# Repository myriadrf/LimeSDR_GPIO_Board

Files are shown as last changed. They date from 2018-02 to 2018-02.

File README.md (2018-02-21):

# LimeSDR GPIO Board

LimeSDR GPIO Board board

The [LimeSDR GPIO Board](https://myriadrf.org/projects/limesdr-gpio-board/) is an expansion board for the LimeSDR family that provides individually settable, bi-directional level-shifted I/O for FPGA GPIO 0-7. Each I/O has a high-voltage and power Darlington drive stage suitable for inductive loads, such as coaxial relays. 

* **Provides bi-directional level shifted IO for GPIO 0-7**
  * 1.2-5.5V IO on J2
* **Each IO has a high voltage and power Darlington drive stage**
  * Acceptable rating 30V 300mA (0-4) 200mA (5-7)
  * Suitable for inductive loads
* **Input/Output are individually switch-able**
* **LimeSDR form factor**
* **Individually pluggable relay connections**

## Contents

The directory structure is as follows:

      hardware/<variant>/<version>/
          Equivalent Circuits/
          Project Outputs/       - BOM, rule check reports, Gerbers, pick & place files, PDFs

      software/
          examples/		 - Simple software examples

## Changelog

| Version | Date | Summary
|---|---|---
| 0402 CAD2 | 21/02/18 | First production version |

## Licence

LimeSDR GPIO Board copyright 2018 [AB Open Ltd](https://abopen.com).

<br />This work is licensed under a <a rel="license" href="http://creativecommons.org/licenses/by/4.0/">Creative Commons Attribution 4.0 International License</a>.

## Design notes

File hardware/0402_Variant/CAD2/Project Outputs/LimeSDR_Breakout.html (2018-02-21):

# /home/karl/Documents/Projects/LimeGPIO/CAD2/LimeSDR_Breakout_0402_version/LimeSDR_Breakout.sch

Thu 30 Nov 2017 16:35:27 GMT

Eeschema 4.0.7-e2-6376~58~ubuntu16.04.1

Component Count:90

Ref | Qnty | Value | Part | Datasheet | Description | Vendor
C1, C3, C4, C6, C7, C8, C11, C12, C15, C16 | 10 | 1uF 16V 0402 | device:C | | Unpolarized capacitor
C2 | 1 | CP | device:CP | | Polarised capacitor
C9, C10, C13, C17, C18, C19, C20, C21 | 8 | 100nF 1206 50V | device:C | | Unpolarized capacitor
C14 | 1 | DNI | device:C | | Unpolarized capacitor
D1 | 1 | GS0T03C_SOT23 | device:D_TVS_x2_AAC | | Bidirectional dual transient-voltage-suppression (TVS) diode (center=pin3)
D2, D3, D4, D5, D6, D7, D8, D9 | 8 | LED | device:LED | | LED generic
J1, J23 | 2 | CONN_02X05 | LimeSDR_Breakout-cache:CONN_02X05
J2 | 1 | CONN_02X05 | LimeSDR_Breakout-cache:CONN_02X05
J3 | 1 | CONN_01X02 | LimeSDR_Breakout-cache:CONN_01X02
J4, J5 | 2 | Screw_Terminal_1x08 | LimeSDR_Breakout-cache:Screw_Terminal_1x08
J6 | 1 | Screw_Terminal_1x02 | LimeSDR_Breakout-cache:Screw_Terminal_1x02
Q1, Q2, Q3, Q4, Q5, Q6, Q7, Q8 | 8 | BC847 | transistors:BC847 | | 45V Vce, 0.8A Ic, NPN, SOT-23
R1, R2, R3, R4, R5, R6, R7, R8 | 8 | 0R | device:R | | Resistor
R25, R26, R27, R28, R29, R30, R31, R32 | 8 | DNI | device:R | | Resistor
R33, R34, R39, R40, R45, R46, R51, R52 | 8 | 47k | device:R | | Resistor
R37, R38, R43, R44, R49, R50, R55, R56 | 8 | 220R | device:R | | Resistor
RN1 | 1 | 10K | device:R_Pack04 | | 4 Resistor network, parallel topology, DIP package
RN2 | 1 | 10k | device:R_Pack04 | | 4 Resistor network, parallel topology, DIP package
SW1 | 1 | DIP_8_SW_IKD0803101 | LimeSDR_Breakout-cache:DIP_8_SW
U1, U2, U3 | 3 | ULN2003A | interface:ULN2003A | | High Voltage, High Current Darlington Transistor Arrays
U4, U5, U6, U7, U8, U9, U10, U11 | 8 | 74LVC1T45 | ABOpen:74LVC1T45

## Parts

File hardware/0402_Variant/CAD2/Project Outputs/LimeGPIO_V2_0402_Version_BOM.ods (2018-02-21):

Ref | Qnty | Kit 100 | Kit 60 | Kit QTY | Value | Footprint | Description | RS PN | ManfPN
C1, C3, C4, C6, C7, C8, C11, C12, C15, C16 | 10 | 1000 | 600 | Reel(90% Full) | 1uF 10V 0402 | 0402 | Unpolarized capacitor |  | C0402C105K8PAC7867
C2 | 1 | 100 | 60 | Bag 50 x2 | CP | TH | Polarised capacitor | 440-6575 | SK063M0100B5S-1012
C9, C10, C13, C17, C18, C19, C20, C21 | 8 | 800 | 480 | Reel(4000) | 100nF 1206 50V | 1206 | Unpolarized capacitor | 870-2776 | C1206C104K5RACTU
D1 | 1 | 100 | 60 | Reel(250) | GS0T03C_SOT23 | SOT23 | Bidirectional dual transient-voltage-suppression (TVS) diode (center=pin3) | 699-7957P | GSOT03C-E3-08
D2, D3, D4, D5, D6, D7, D8, D9 | 8 | 800 | 480 | Reel(4000) | LED | 0805 | LED generic (green) | 121-7785 | LG971
J23 | 1 | 100 | 60 | Tube 80 | CONN_02X05 | SM |  | 451-663 | FTSH-105-04-F-DV
J2 | 1 | 100 | 60 | Tube 120 | CONN_02X05 | SM |  |  | HTSS-105-01-T-DW
J3 | 1 | 100 | 60 | Bag 25x4 | CONN_01X02 | TH |  | 251-8086 | W81102T3825RC
J4, J5 | 2 | 200 | 120 | Box Loose x120 | Screw_Terminal_1x08 | TH |  | 189-6161 | 1757307
J6 | 1 | 100 | 60 | Bag loose 12x5 | Screw_Terminal_1x02 | TH |  | 189-6105 | 1757242
Q1, Q2, Q3, Q4, Q5, Q6, Q7, Q8 | 8 | 800 | 480 | Reel(90% Full) | BC847 | SOT23 | 45V Vce, 0.8A Ic, NPN, SOT-23 | 717-1578 | BC847C
R1, R2, R3, R4, R5, R6, R7, R8 | 8 | 800 | 480 | Reel(70% Full) | 0R | 0402 | Resistor |  | RC0402JR-070RL
R33, R34, R39, R40, R45, R46, R51, R52 | 8 | 800 | 480 | Reel(90% Full) | 47k | 0402 | Resistor |  | KMB-1610310072
R37, R38, R43, R44, R49, R50, R55, R56 | 8 | 800 | 480 | Reel(70% Full) | 220R | 0402 | Resistor |  | KMB-1701190047
RN1,RN2 | 1 | 100 | 60 | Reel(300) | 10K | 4x0603 | 4 Resistor network, parallel topology, DIP package | 426-229P | CAY16-103J4LF
SW1 | 1 | 100 | 60 | Tube 104 | DIP_8_SW_IKD0803101 | SM |  | 189-6010 | IKD0803101
U1, U2, U3 | 3 | 300 | 180 | Reelx2(200+200) | ULN2003A | SOIC | High Voltage, High Current Darlington Transistor Arrays | 251-8503 | ULN2003D1013TR
U4, U5, U6, U7, U8, U9, U10, U11 | 8 | 800 | 480 | Reel(3000) | 74LVC1T45 | SC70 – 6pin |  | 922-2385 | SN74LVC1T45DCKR

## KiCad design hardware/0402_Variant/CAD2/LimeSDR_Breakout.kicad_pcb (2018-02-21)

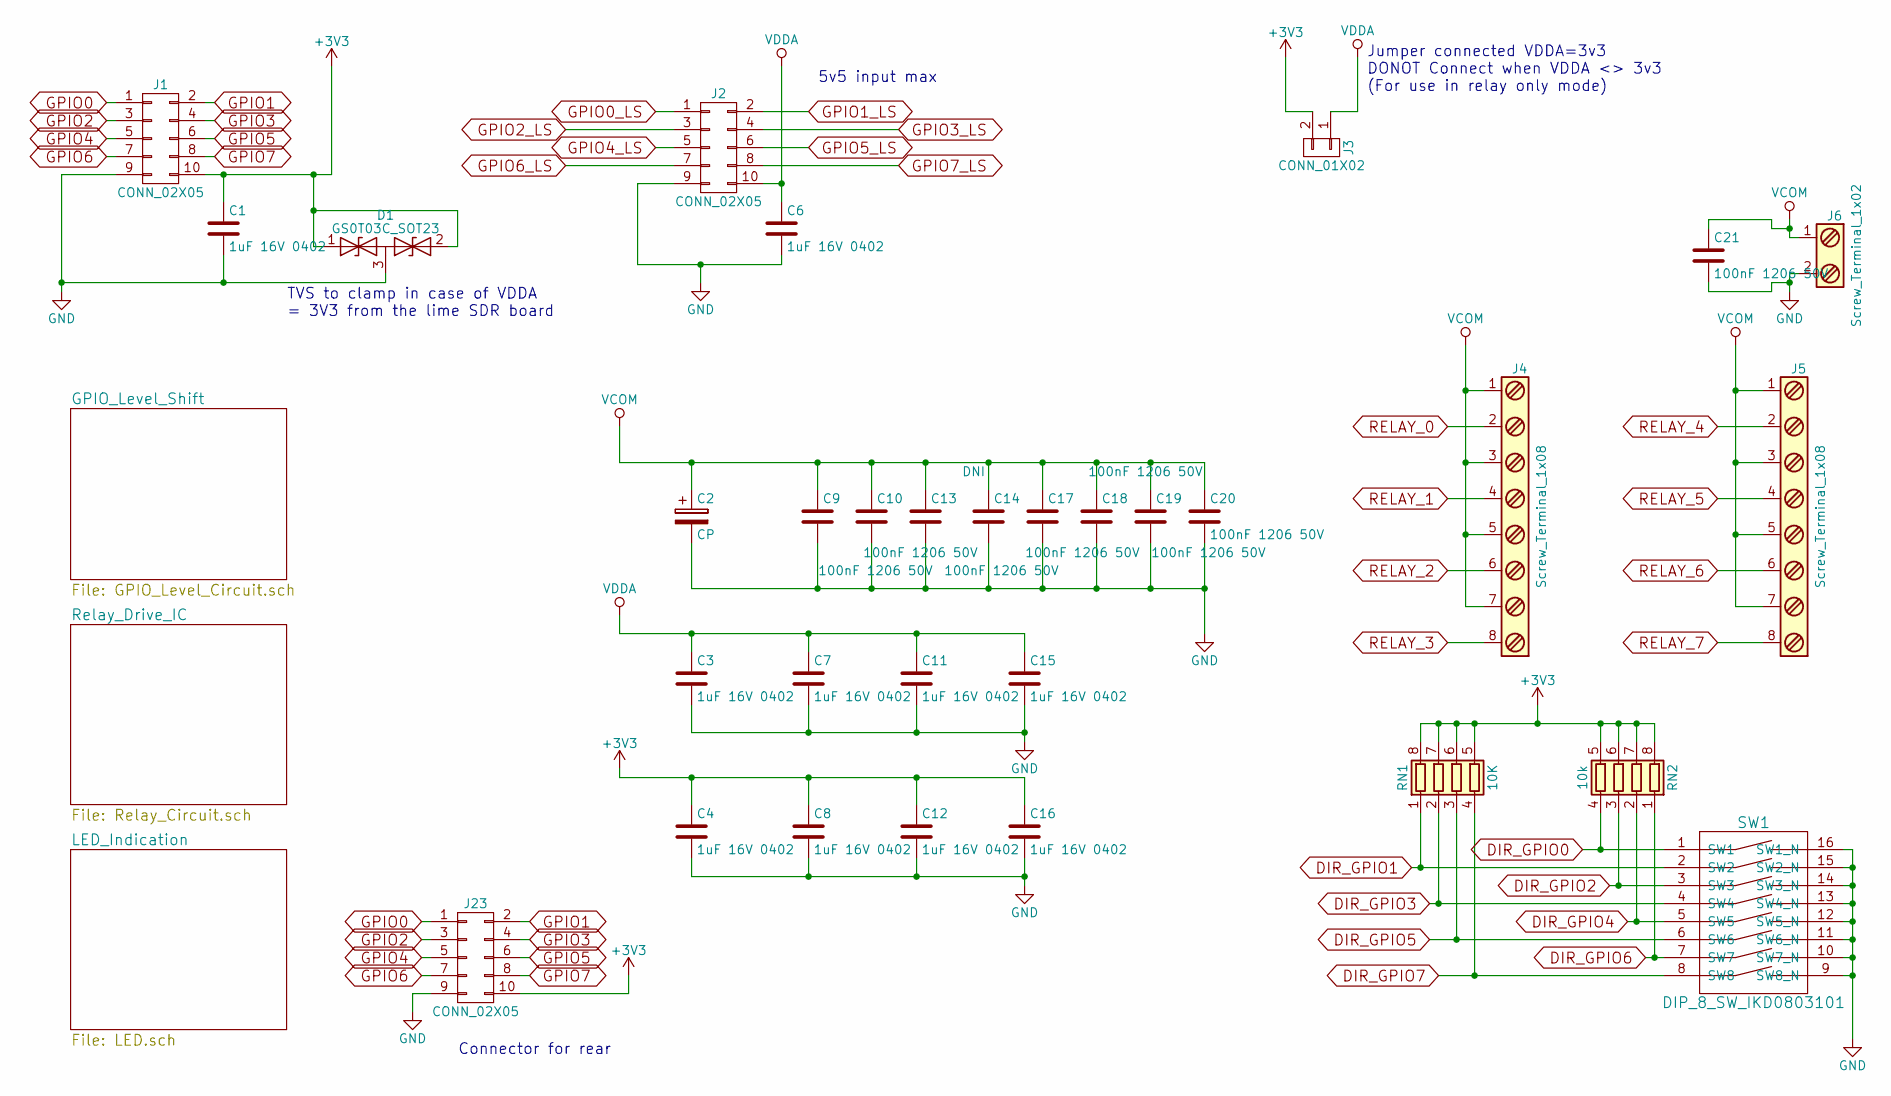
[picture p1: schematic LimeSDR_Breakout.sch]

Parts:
C1, C3, C4, C6, C7, C8, C11, C12, C15, C16: 1uF 16V 0402; C_0402
C2: CP; CP_Radial_D10.0mm_P5.00mm
C9, C10, C13, C17, C18, C19, C20, C21: 100nF 1206 50V; C_1206
C14: DNI; C_1206
D1: GS0T03C_SOT23; SOT-23
J1, J23: CONN_02X05; Pin_Header_Straight_2x05_Pitch1.27mm_SMD
J2: CONN_02X05; Pin_Header_Straight_2x05_Pitch2.54mm_SMD
J3: CONN_01X02; Pin_Header_Straight_1x02_Pitch2.54mm
J4, J5: Screw_Terminal_1x08; RS_189_6060_R
J6: Screw_Terminal_1x02; RS_189-6105_reversed
RN1: 10K; R_Array_Convex_4x1206
RN2: 10k; R_Array_Convex_4x1206
SW1: DIP_8_SW_IKD0803101; DIP_W7.40_Gull-Wing-J

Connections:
+3V3: C1.1, C4.1, C8.1, C12.1, C16.1, D1.1 (A1), D1.2 (A2), J1.10, J3.2, J23.10, RN1.5 (R4.2), RN1.6 (R3.2), RN1.7 (R2.2), RN1.8 (R1.2), RN2.5 (R4.2), RN2.6 (R3.2), RN2.7 (R2.2), RN2.8 (R1.2); also elsewhere on the board
DIR_GPIO0: RN2.4 (R4.1), SW1.1 (SW1); also elsewhere on the board
DIR_GPIO1: RN1.1 (R1.1), SW1.2 (SW2); also elsewhere on the board
DIR_GPIO2: RN2.3 (R3.1), SW1.3 (SW3); also elsewhere on the board
DIR_GPIO3: RN1.2 (R2.1), SW1.4 (SW4); also elsewhere on the board
DIR_GPIO4: RN2.2 (R2.1), SW1.5 (SW5); also elsewhere on the board
DIR_GPIO5: RN1.3 (R3.1), SW1.6 (SW6); also elsewhere on the board
DIR_GPIO6: RN2.1 (R1.1), SW1.7 (SW7); also elsewhere on the board
DIR_GPIO7: RN1.4 (R4.1), SW1.8 (SW8); also elsewhere on the board
GND: C1.2, C2.2, C3.2, C4.2, C6.2, C7.2, C8.2, C9.2, C10.2, C11.2, C12.2, C13.2, C14.2, C15.2, C16.2, C17.2, C18.2, C19.2, C20.2, C21.2, D1.3 (common), J1.9, J2.9, J6.2, J23.9, SW1.9 (SW8_N), SW1.10 (SW7_N), SW1.11 (SW6_N), SW1.12 (SW5_N), SW1.13 (SW4_N), SW1.14 (SW3_N), SW1.15 (SW2_N), SW1.16 (SW1_N); also elsewhere on the board
GPIO0: J1.1, J23.1; also elsewhere on the board
GPIO0_LS: J2.1; also elsewhere on the board
GPIO1: J1.2, J23.2; also elsewhere on the board
GPIO1_LS: J2.2; also elsewhere on the board
GPIO2: J1.3, J23.3; also elsewhere on the board
GPIO2_LS: J2.3; also elsewhere on the board
GPIO3: J1.4, J23.4; also elsewhere on the board
GPIO3_LS: J2.4; also elsewhere on the board
GPIO4: J1.5, J23.5; also elsewhere on the board
GPIO4_LS: J2.5; also elsewhere on the board
GPIO5: J1.6, J23.6; also elsewhere on the board
GPIO5_LS: J2.6; also elsewhere on the board
GPIO6: J1.7, J23.7; also elsewhere on the board
GPIO6_LS: J2.7; also elsewhere on the board
GPIO7: J1.8, J23.8; also elsewhere on the board
GPIO7_LS: J2.8; also elsewhere on the board
RELAY_0: J4.2; also elsewhere on the board
RELAY_1: J4.4; also elsewhere on the board
RELAY_2: J4.6; also elsewhere on the board
RELAY_3: J4.8; also elsewhere on the board
RELAY_4: J5.2; also elsewhere on the board
RELAY_5: J5.4; also elsewhere on the board
RELAY_6: J5.6; also elsewhere on the board
RELAY_7: J5.8; also elsewhere on the board
VCOM: C2.1, C9.1, C10.1, C13.1, C14.1, C17.1, C18.1, C19.1, C20.1, C21.1, J4.1, J4.3, J4.5, J4.7, J5.1, J5.3, J5.5, J5.7, J6.1; also elsewhere on the board
VDDA: C3.1, C6.1, C7.1, C11.1, C15.1, J2.10, J3.1; also elsewhere on the board

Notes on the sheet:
5v5 input max
TVS to clamp in case of VDDA = 3V3 from the lime SDR board
Jumper connected VDDA=3v3 DONOT Connect when VDDA <> 3v3 (For use in relay only mode)
Connector for rear

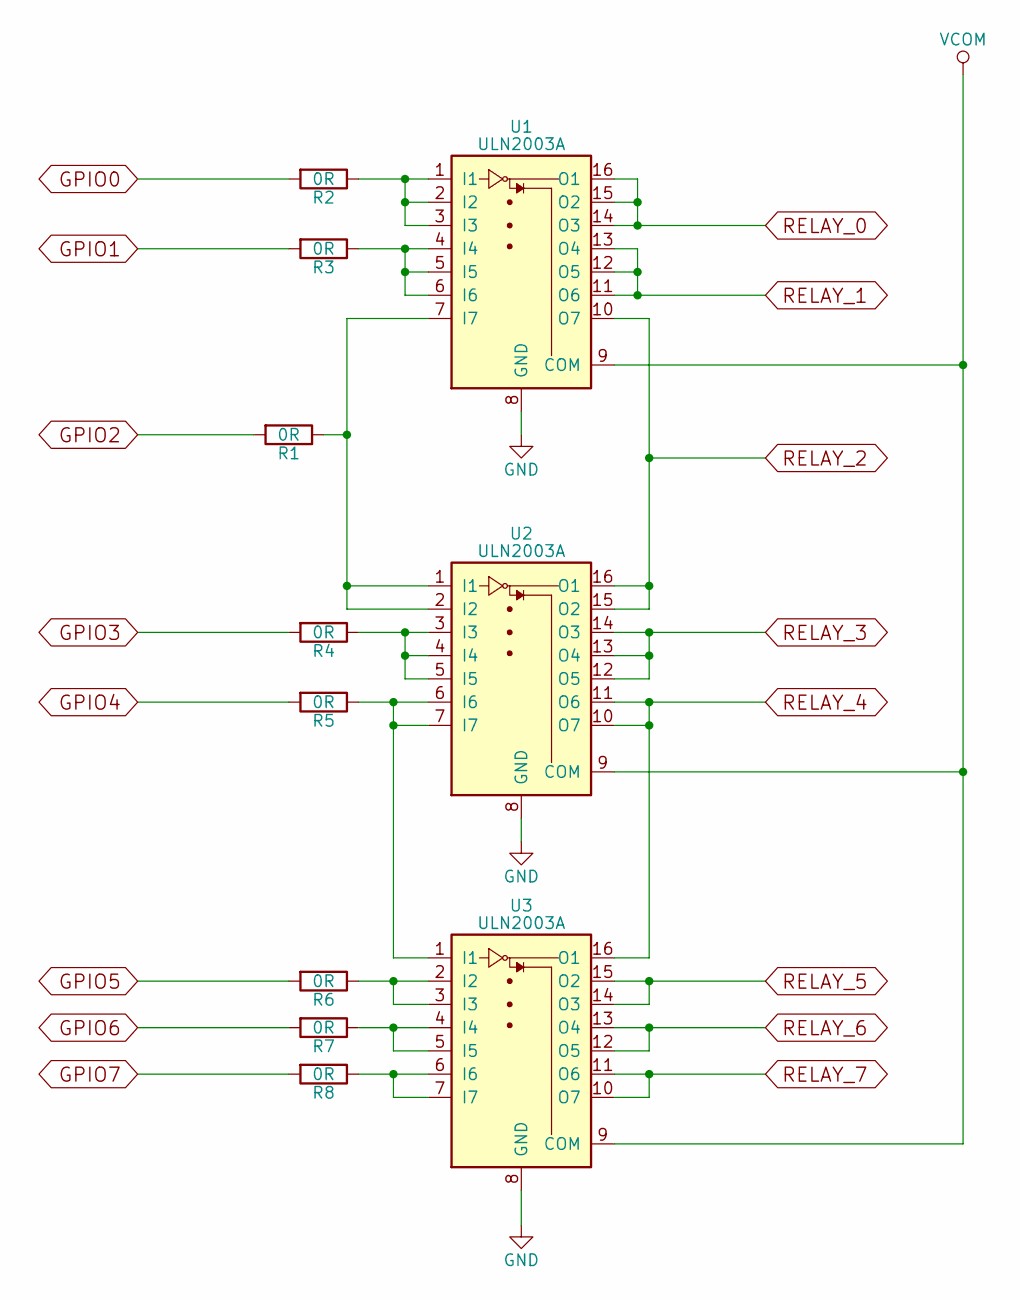
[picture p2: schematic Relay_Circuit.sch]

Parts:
R1, R2, R3, R4, R5, R6, R7, R8: 0R; C_0402
U1, U2, U3: ULN2003A; SOIC-16_3.9x9.9mm_Pitch1.27mm

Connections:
GND: U1.8 (GND), U2.8 (GND), U3.8 (GND); also elsewhere on the board
GPIO0: R2.2; also elsewhere on the board
GPIO1: R3.2; also elsewhere on the board
GPIO2: R1.2; also elsewhere on the board
GPIO3: R4.2; also elsewhere on the board
GPIO4: R5.2; also elsewhere on the board
GPIO5: R6.2; also elsewhere on the board
GPIO6: R7.2; also elsewhere on the board
GPIO7: R8.2; also elsewhere on the board
unnamed: R1.1, U1.7 (I7), U2.1 (I1), U2.2 (I2)
unnamed: R2.1, U1.1 (I1), U1.2 (I2), U1.3 (I3)
unnamed: R3.1, U1.4 (I4), U1.5 (I5), U1.6 (I6)
unnamed: R4.1, U2.3 (I3), U2.4 (I4), U2.5 (I5)
unnamed: R5.1, U2.6 (I6), U2.7 (I7), U3.1 (I1)
unnamed: R6.1, U3.2 (I2), U3.3 (I3)
unnamed: R7.1, U3.4 (I4), U3.5 (I5)
unnamed: R8.1, U3.6 (I6), U3.7 (I7)
RELAY_0: U1.14 (O3), U1.15 (O2), U1.16 (O1); also elsewhere on the board
RELAY_1: U1.11 (O6), U1.12 (O5), U1.13 (O4); also elsewhere on the board
RELAY_2: U1.10 (O7), U2.15 (O2), U2.16 (O1); also elsewhere on the board
RELAY_3: U2.12 (O5), U2.13 (O4), U2.14 (O3); also elsewhere on the board
RELAY_4: U2.10 (O7), U2.11 (O6), U3.16 (O1); also elsewhere on the board
RELAY_5: U3.14 (O3), U3.15 (O2); also elsewhere on the board
RELAY_6: U3.12 (O5), U3.13 (O4); also elsewhere on the board
RELAY_7: U3.10 (O7), U3.11 (O6); also elsewhere on the board
VCOM: U1.9 (COM), U2.9 (COM), U3.9 (COM); also elsewhere on the board

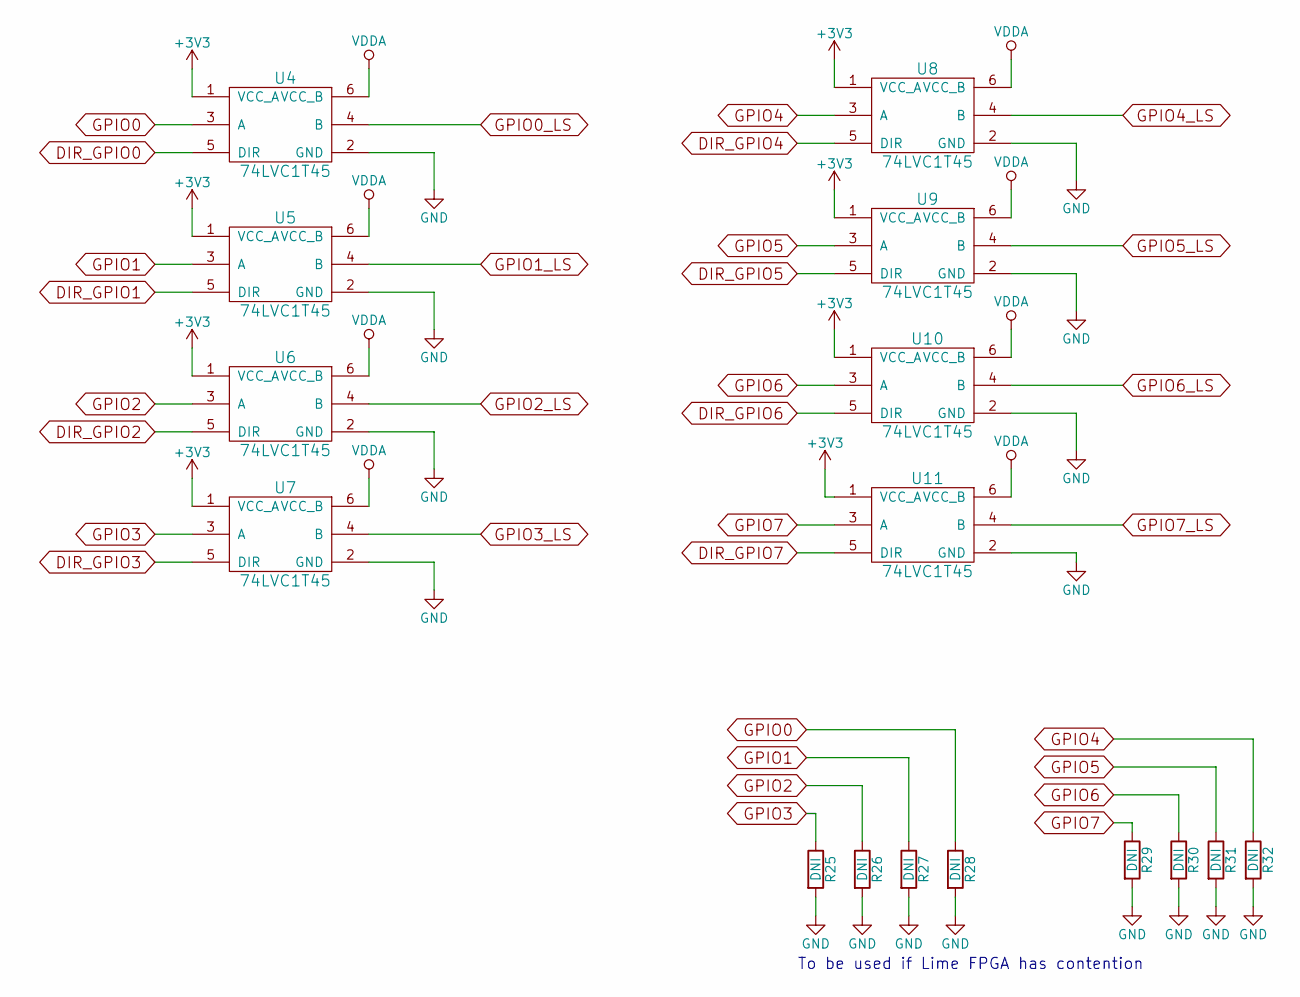
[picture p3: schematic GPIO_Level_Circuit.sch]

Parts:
R25, R26, R27, R28, R29, R30, R31, R32: DNI; C_0402
U4, U5, U6, U7, U8, U9, U10, U11: 74LVC1T45; SOT-363_SC-70-6_Handsoldering

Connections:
+3V3: U4.1 (VCC_A), U5.1 (VCC_A), U6.1 (VCC_A), U7.1 (VCC_A), U8.1 (VCC_A), U9.1 (VCC_A), U10.1 (VCC_A), U11.1 (VCC_A); also elsewhere on the board
DIR_GPIO0: U4.5 (DIR); also elsewhere on the board
DIR_GPIO1: U5.5 (DIR); also elsewhere on the board
DIR_GPIO2: U6.5 (DIR); also elsewhere on the board
DIR_GPIO3: U7.5 (DIR); also elsewhere on the board
DIR_GPIO4: U8.5 (DIR); also elsewhere on the board
DIR_GPIO5: U9.5 (DIR); also elsewhere on the board
DIR_GPIO6: U10.5 (DIR); also elsewhere on the board
DIR_GPIO7: U11.5 (DIR); also elsewhere on the board
GND: R25.2, R26.2, R27.2, R28.2, R29.2, R30.2, R31.2, R32.2, U4.2 (GND), U5.2 (GND), U6.2 (GND), U7.2 (GND), U8.2 (GND), U9.2 (GND), U10.2 (GND), U11.2 (GND); also elsewhere on the board
GPIO0: R28.1, U4.3 (A); also elsewhere on the board
GPIO0_LS: U4.4 (B); also elsewhere on the board
GPIO1: R27.1, U5.3 (A); also elsewhere on the board
GPIO1_LS: U5.4 (B); also elsewhere on the board
GPIO2: R26.1, U6.3 (A); also elsewhere on the board
GPIO2_LS: U6.4 (B); also elsewhere on the board
GPIO3: R25.1, U7.3 (A); also elsewhere on the board
GPIO3_LS: U7.4 (B); also elsewhere on the board
GPIO4: R32.1, U8.3 (A); also elsewhere on the board
GPIO4_LS: U8.4 (B); also elsewhere on the board
GPIO5: R31.1, U9.3 (A); also elsewhere on the board
GPIO5_LS: U9.4 (B); also elsewhere on the board
GPIO6: R30.1, U10.3 (A); also elsewhere on the board
GPIO6_LS: U10.4 (B); also elsewhere on the board
GPIO7: R29.1, U11.3 (A); also elsewhere on the board
GPIO7_LS: U11.4 (B); also elsewhere on the board
VDDA: U4.6 (VCC_B), U5.6 (VCC_B), U6.6 (VCC_B), U7.6 (VCC_B), U8.6 (VCC_B), U9.6 (VCC_B), U10.6 (VCC_B), U11.6 (VCC_B); also elsewhere on the board

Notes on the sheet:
To be used if Lime FPGA has contention

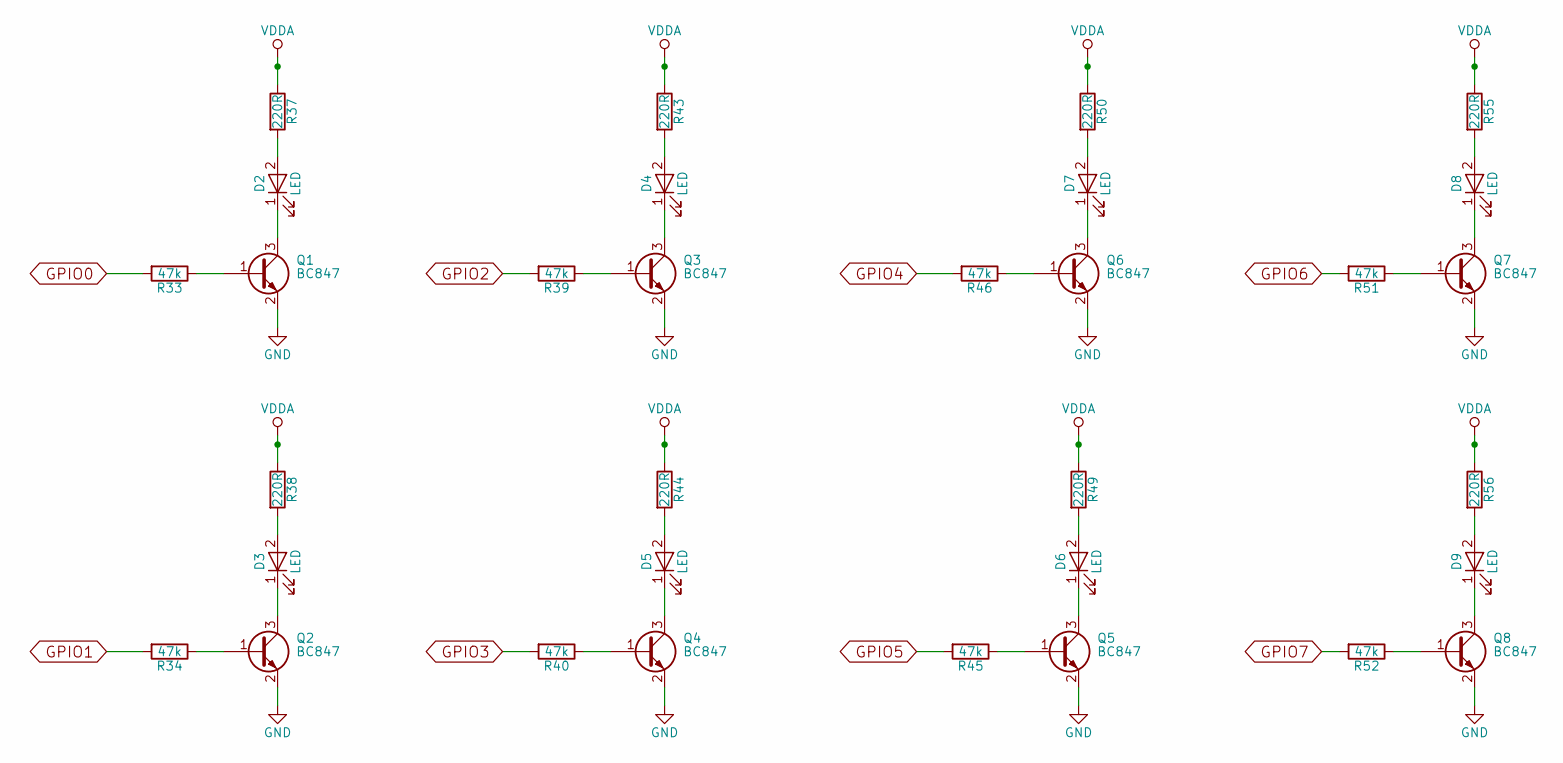
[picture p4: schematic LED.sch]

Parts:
D2, D3, D4, D5, D6, D7, D8, D9: LED; LED_0805
Q1, Q2, Q3, Q4, Q5, Q6, Q7, Q8: BC847; SOT-23
R33, R34, R39, R40, R45, R46, R51, R52: 47k; C_0402
R37, R38, R43, R44, R49, R50, R55, R56: 220R; C_0402

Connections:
GND: Q1.2 (E), Q2.2 (E), Q3.2 (E), Q4.2 (E), Q5.2 (E), Q6.2 (E), Q7.2 (E), Q8.2 (E); also elsewhere on the board
GPIO0: R33.2; also elsewhere on the board
GPIO1: R34.2; also elsewhere on the board
GPIO2: R39.2; also elsewhere on the board
GPIO3: R40.2; also elsewhere on the board
GPIO4: R46.2; also elsewhere on the board
GPIO5: R45.2; also elsewhere on the board
GPIO6: R51.2; also elsewhere on the board
GPIO7: R52.2; also elsewhere on the board
unnamed: D2.1 (K), Q1.3 (C)
unnamed: D2.2 (A), R37.2
unnamed: D3.1 (K), Q2.3 (C)
unnamed: D3.2 (A), R38.2
unnamed: D4.1 (K), Q3.3 (C)
unnamed: D4.2 (A), R43.2
unnamed: D5.1 (K), Q4.3 (C)
unnamed: D5.2 (A), R44.2
unnamed: D6.1 (K), Q5.3 (C)
unnamed: D6.2 (A), R49.2
unnamed: D7.1 (K), Q6.3 (C)
unnamed: D7.2 (A), R50.2
unnamed: D8.1 (K), Q7.3 (C)
unnamed: D8.2 (A), R55.2
unnamed: D9.1 (K), Q8.3 (C)
unnamed: D9.2 (A), R56.2
unnamed: Q1.1 (B), R33.1
unnamed: Q2.1 (B), R34.1
unnamed: Q3.1 (B), R39.1
unnamed: Q4.1 (B), R40.1
unnamed: Q5.1 (B), R45.1
unnamed: Q6.1 (B), R46.1
unnamed: Q7.1 (B), R51.1
unnamed: Q8.1 (B), R52.1
VDDA: R37.1, R38.1, R43.1, R44.1, R49.1, R50.1, R55.1, R56.1; also elsewhere on the board

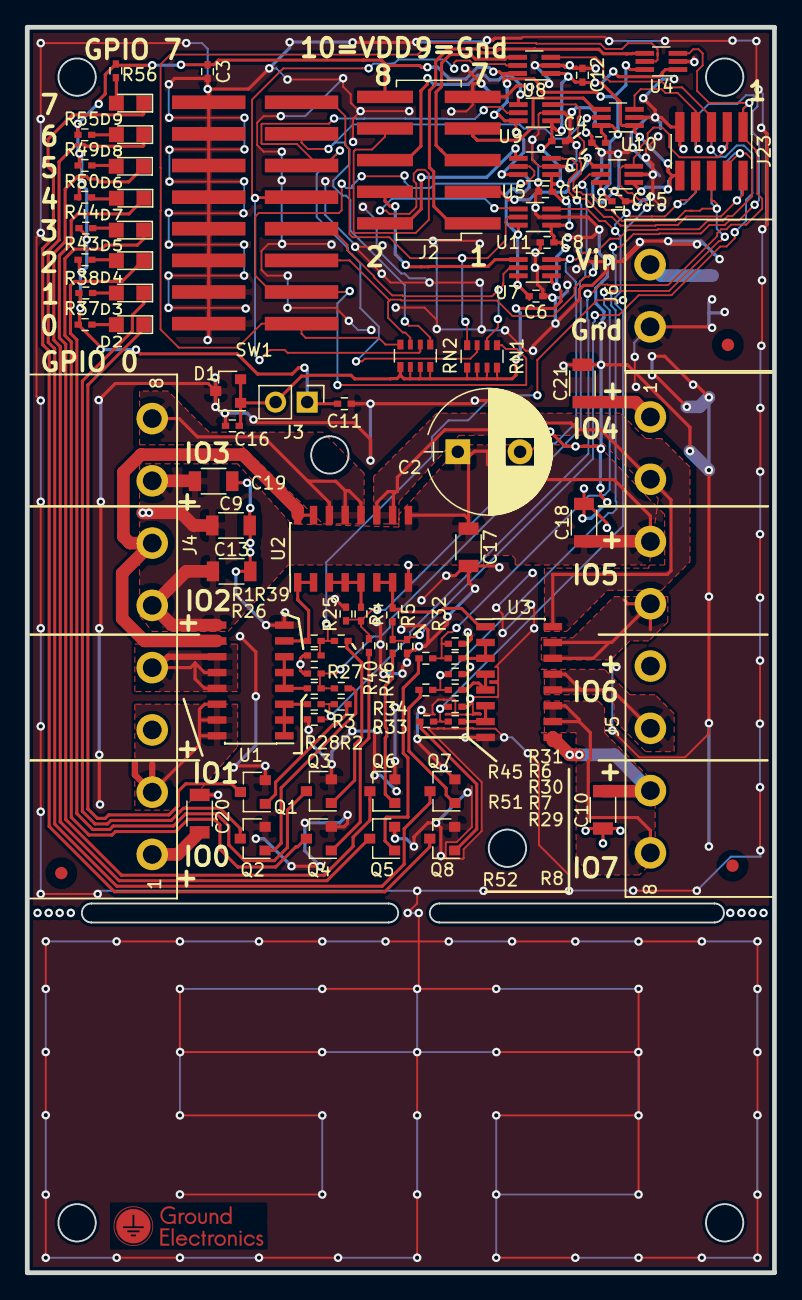
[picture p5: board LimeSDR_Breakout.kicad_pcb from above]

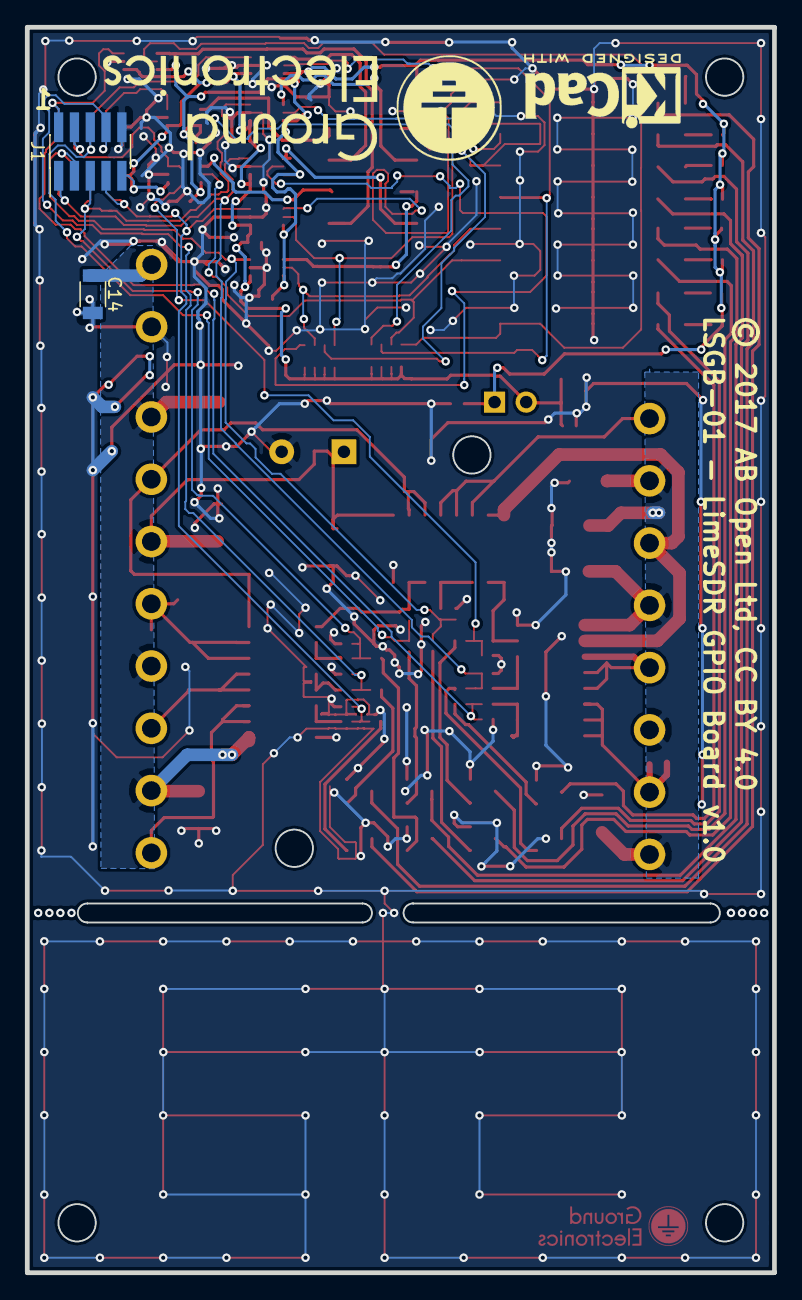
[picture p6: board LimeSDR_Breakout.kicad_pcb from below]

Board: 2 copper layers, 60.0 x 100.0 mm, 90 parts (2 on the bottom side), 68 nets.

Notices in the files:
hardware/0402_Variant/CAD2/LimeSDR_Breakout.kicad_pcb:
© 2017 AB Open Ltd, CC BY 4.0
